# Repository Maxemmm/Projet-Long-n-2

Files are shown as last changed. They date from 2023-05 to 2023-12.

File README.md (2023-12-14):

# Room Monitoring Device - Projet Long n°2
## _EI2I4 HF_ | _Groupe 2_

The goal of this project is to develop a complete device that can measure several physical datas and to make them available through a Human Machine Interface (HMI) on an internet application. This project will allow to recover and format the data measured by the sensors and then send them to a server (Cloud) thanks to the long range and low power technology (LPWAN).

## Features
- Autonomous: Rechargeable LiPo battery and indoor solar panels as power source
- Communication of information by LPWAN network (LoRAWAN): Data sending every 10 minutes (configurable)
- On/off button : Allows an instantaneous measurement
- LED that lights up for a few seconds when the system is started.
- Data display in graphical form on an internet application: Ubidots STEM during the development phase and an internal Polytech website for the final rendering of the project.

## Components
In order to realize this project, we had to find components that best respond to the imposed specifications by focusing on the main constraint which is the low consumption of the system:

| Components | Price |
| --- | --- |
| [E-Ink Screen](https://www.digikey.fr/en/products/detail/adafruit-industries-llc/4197/10060730) | 21.10€ |  
| [Indoor solar kit](https://www.mouser.fr/ProductDetail/PowerFilm/DEV-BASIC?qs=BJlw7L4Cy7%2Fw4dHFXPm5kg%3D%3D) | 55.97€ |
| [CO2, T°, Humidity Sensor](https://www.digikey.fr/fr/products/detail/seeed-technology-co.,-ltd/101020952/14672116?utm_adgroup=&utm_source=google&utm_medium=cpc&utm_campaign=PMAX%20Shopping_Product_Development%20Board&utm_term=&productid=14672116&gclid=CjwKCAiA3KefBhByEiwAi2LDHGC3sSf3_wtaYPH630ib0XKAaLsoO_e8GBNamO-FCIEC66xhhMLAGhoCcFoQAvD_BwE) | 48.36€ |
| [Noise Sensor](https://www.gotronic.fr/art-module-micro-mems-fermion-sen0487-34167.htm) | 3.50€ |
| [Light Sensor](https://www.digikey.fr/fr/products/detail/adafruit-industries-llc/5378/16056942?productid=16056942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) | 4.64€ |
| [Battery](https://www.gotronic.fr/art-accu-lipo-3-7-vcc-1000-mah-pr523450-5813.htm) | 9.90€ |

For a total cost of 143.47€, we created [insert project name]. Responding to the specifications imposed, this energy autonomous system allows to manage the constants of a room in order to respect the sanitary conditions imposed by the school, or by any other organization.

## User interface
We used a Ubitdots STEM user interface which is a perfect environment to send data from our Arduino board to the cloud. The dashboard then allows the visualisation and monitoring of all this data remotely
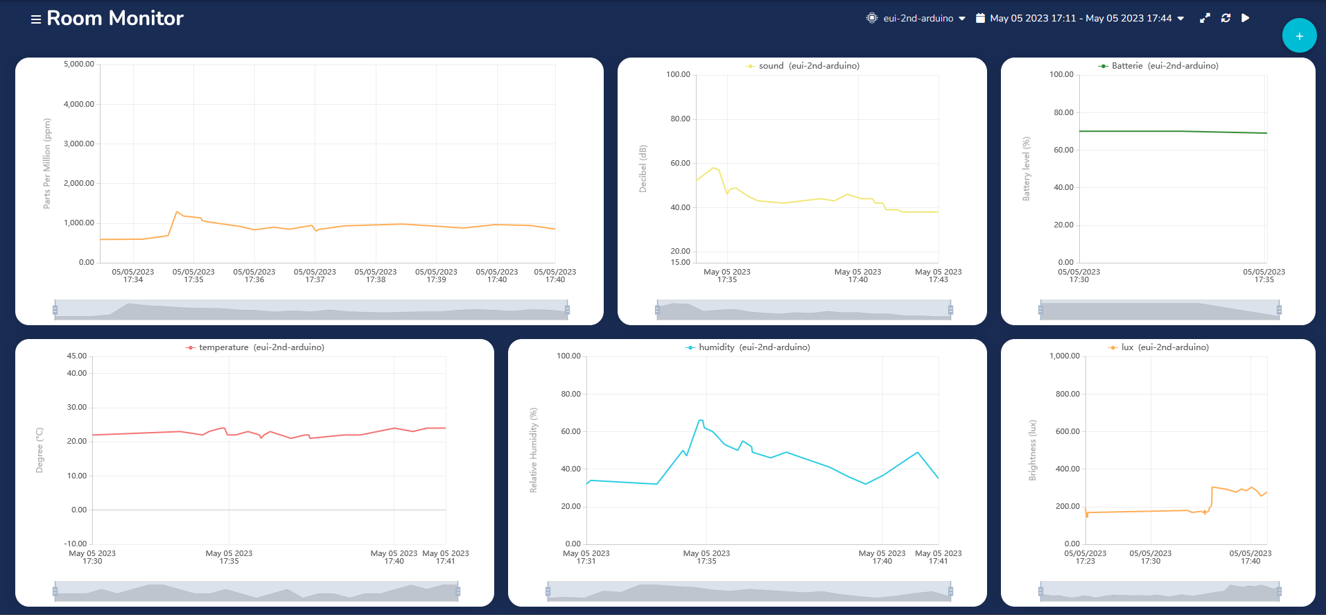
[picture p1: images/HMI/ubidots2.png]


## 3D Modeling
For this project I made a box to contain all the components as well as the PCB on which is mounted the Arduino MKR 1310 board and the indoors solar cells that allow the system to be self-sufficient in terms of energy.

### 3D Folder tree

```bash
.
├── Projet_rev11.f3z
├── Boitier_rev05.f3d
├── Bouton_rev01.f3d
├── Dos-Boitier_rev02.f3d
├── Panneau-Solaire-Haut_rev02
├── Panneau-Solaire-Haut
│   ├── Cache-Panneau-Solaire-Haut
│   └── Support-Panneau-Solaire-Haut
├── Panneau-Solaire-Cotes_rev04
└── Panneau-Solaire-Cotes
    ├── Cache-Panneau-Solaire-Cotes
    └── Support-Panneau-Solaire-Cotes
```

### 3D Model
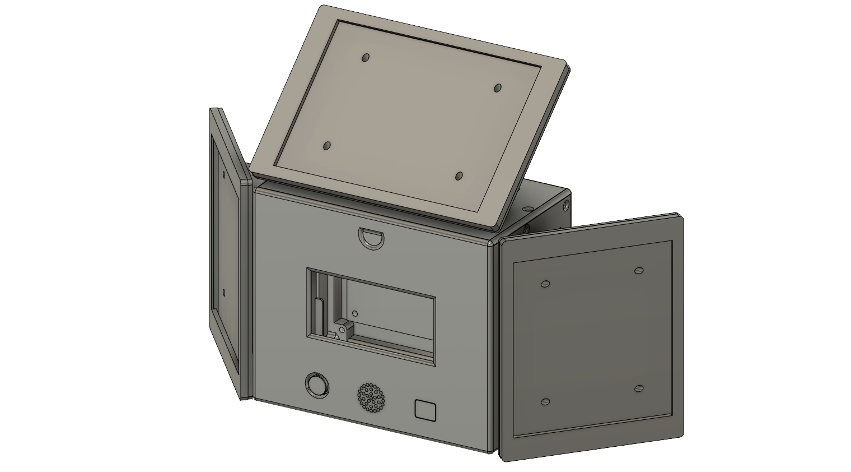
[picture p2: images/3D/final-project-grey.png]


<details>
<summary>Exploaded view</summary>

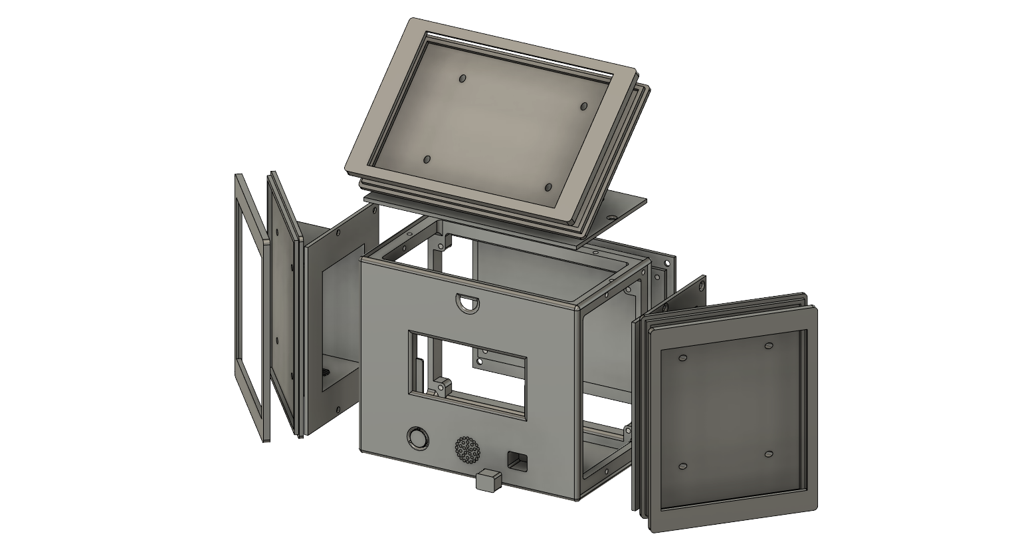
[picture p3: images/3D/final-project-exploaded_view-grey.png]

</details>

The model includes a total of 9 pieces:
| Part | Nb | Description |
| --- | --- | --- |
| Boitier | x1 | The box is the structure of the system and allows to hold the different components and sensors of the project. |
| Dos-Boitier | x1 | The back of the case is removable and allows to fix the PCB directly on it. By removing this part, you can access the inside of the box. |
| Bouton | x1 | The custom button allows instant measurement. |
| Support-Panneau-Solaire-Haut | x1 | This support must be fixed on the top of the box and allows to hold the upper solar panel. |
| Cache-Panneau-Solaire-Haut | x1 |This cover allows the top solar panel to be plated against the support. |
| Support-Panneau-Solaire-Cotes | x2 | This support must be fixed on the side of the box and allows to hold the side solar panel. |
| Cache-Panneau-Solaire-Cotes| x2 | This cover allows the side solar panel to be pressed against the support. |

### Assembling
To assemble the parts together you need the parts listed above as well as the material below:
| Hardware | Nb | Type |  Description |
| --- | --- | --- | --- |
| Screws | x16 | M3x8mm | Allows to fix the upper and lateral supports of the solar panels. |
| Anti-skid pads | x4 | 10x3mm | Allows to elevate the case and to give it more grip on the ground. |

## Electronic schematics
We have made a printed circuit board that allows us firstly to have a significant reduction in the number of wires inside the box that houses the system and secondly to be able to weld the components and connect the sensors to their intended locations.
<details>
<summary>Electrical scheme</summary>

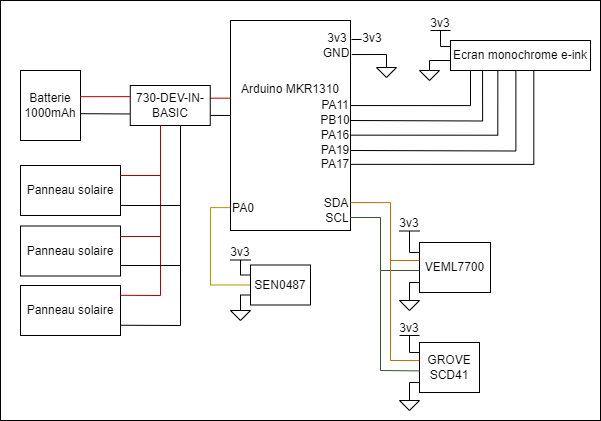
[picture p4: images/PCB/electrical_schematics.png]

</details>

<details>
<summary>Printed Circuit Board</summary>

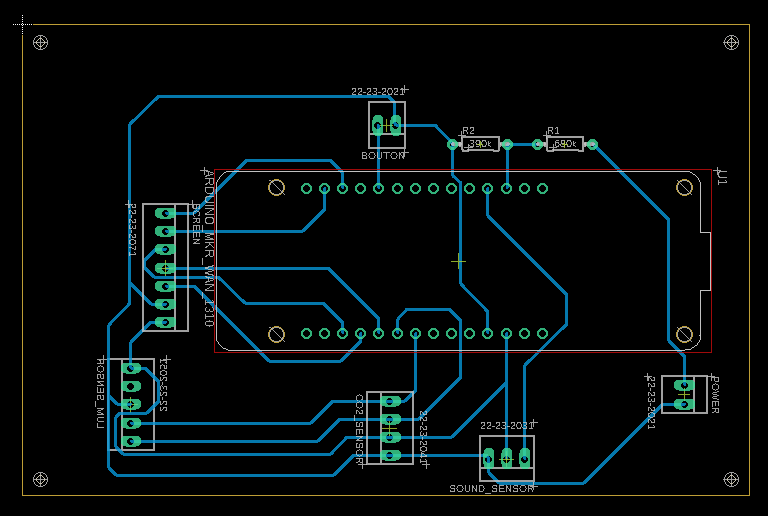
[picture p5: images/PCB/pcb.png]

</details>

## Consumption measurement
In this section, we will focus on the production and consumption of electricity. In order to make the device autonomous, we added the DEV-BASIC Powerfilm module, which includes two interior solar panels (we only used these), two exterior solar panels, an electronic board, and a battery. We also had two ECS300 solar panels available.

Therefore, we connected these four solar panels in parallel (to increase the current as much as possible) and connected them to the "Solar" input of the board. Then, we connected the battery to the "battery" output of the board and connected the "Vout" part of the board to the rest of the circuit.

Thanks to this setup, the solar panels continuously charge the battery, which then powers the board. Once the setup was completed, we measured the electricity production and found that our production was about 0.990mA/h on average (~380 lumens).

After that, we measured the consumption of the setup and found that it consumed an average of XXXX mA, thanks to code optimization and activated deep sleep and standby modes. <br>

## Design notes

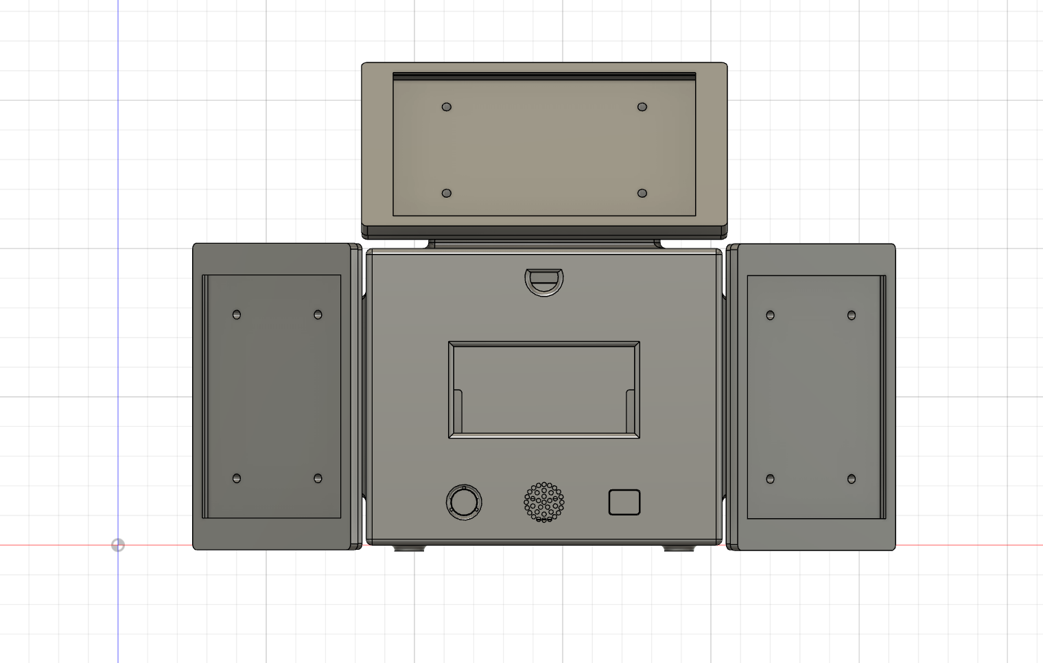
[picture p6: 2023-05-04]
images/3D/stock/front.png

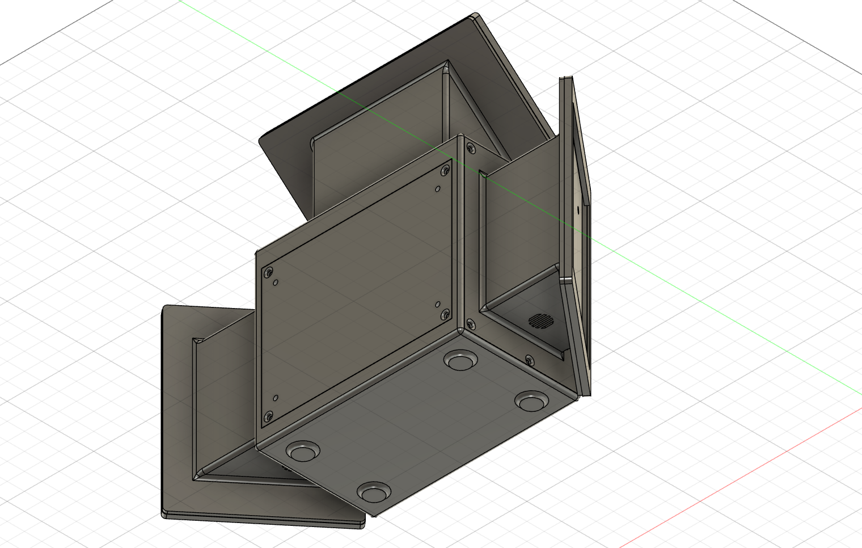
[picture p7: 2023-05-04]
images/3D/stock/back-bottom-right.png

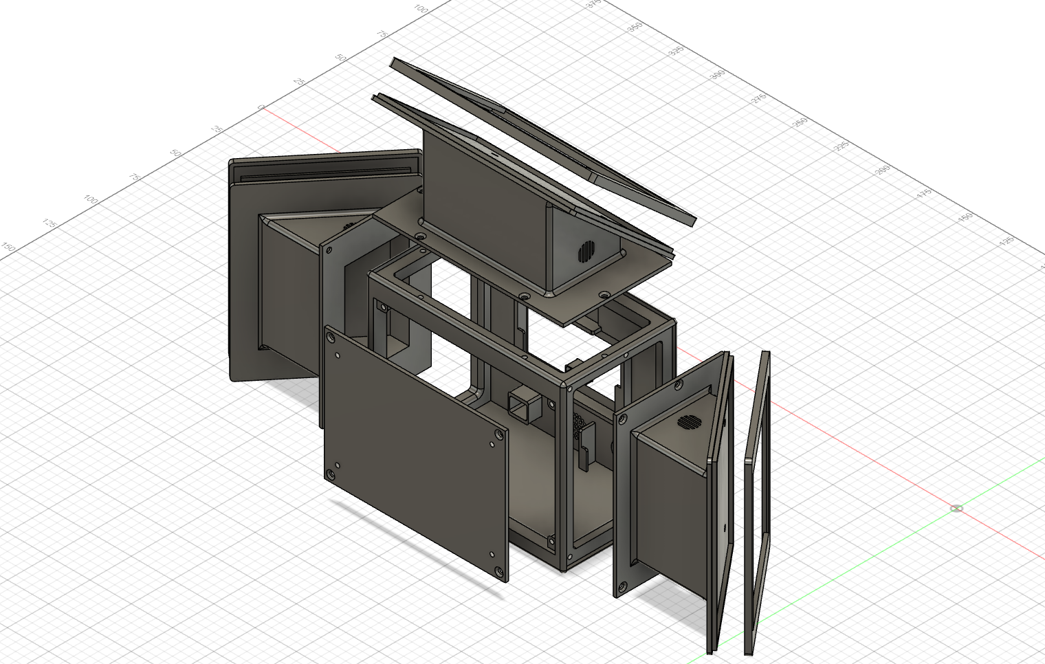
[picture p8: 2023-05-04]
images/3D/back-upper-right.png

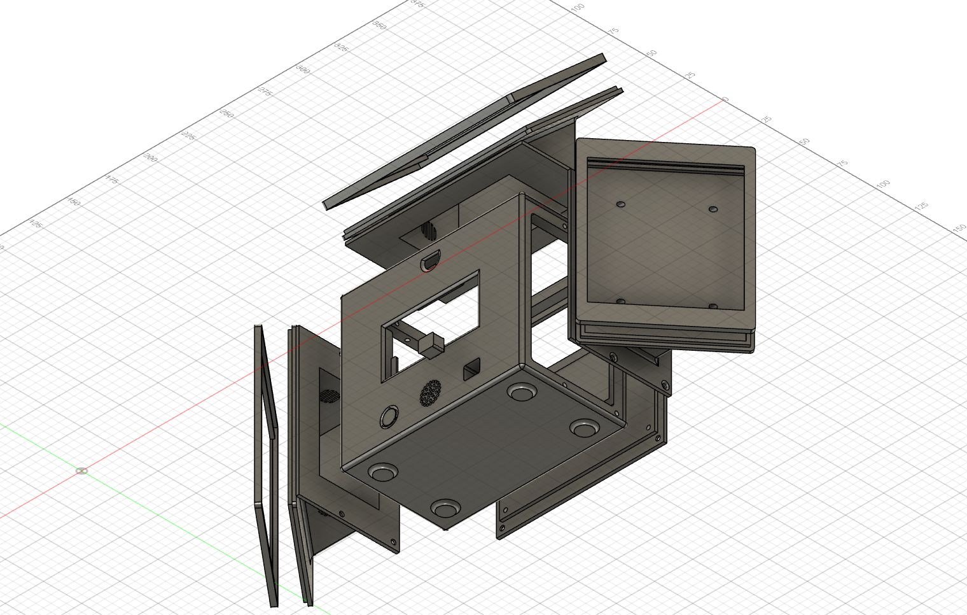
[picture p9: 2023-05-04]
images/3D/front-bottom-right.png

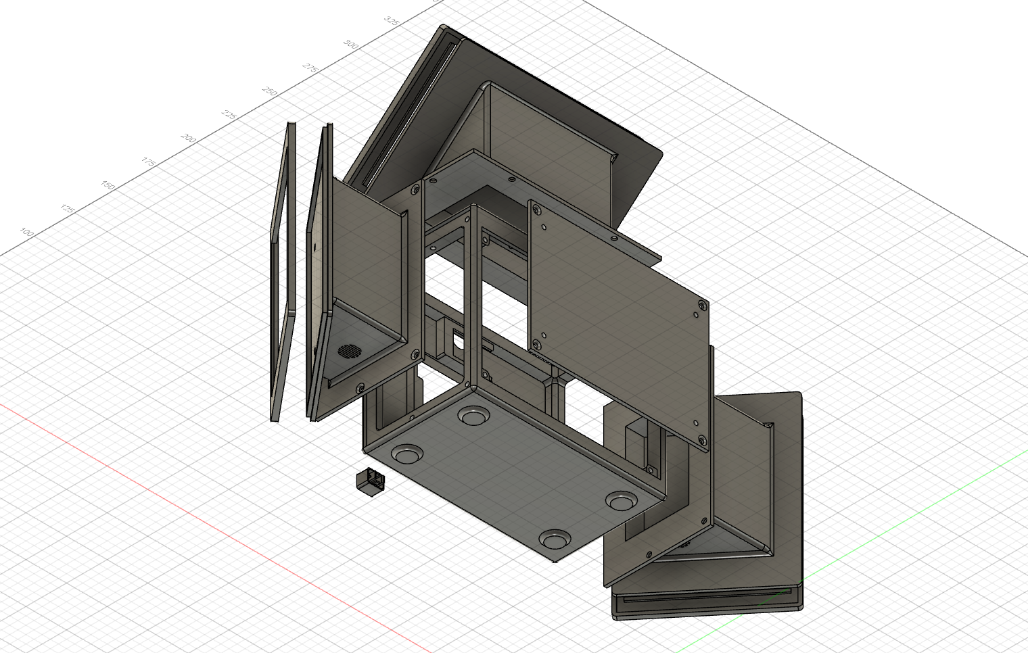
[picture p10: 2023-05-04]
images/3D/back-bottom-left.png

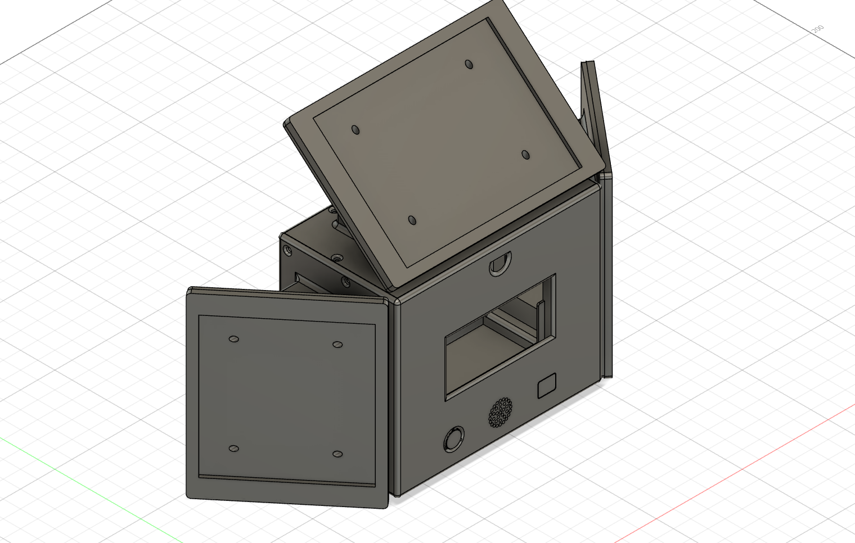
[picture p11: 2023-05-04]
images/3D/stock/front-upper-left.png

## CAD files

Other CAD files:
3D/Boitier_rev05.f3d
3D/Boitier_rev06.f3d
3D/Bouton_rev01.f3d
3D/Dos-Boitier_rev02.f3d
3D/Panneau-Solaire-Cotes/Cache-Panneau-Solaire-Cote.f3d
3D/Panneau-Solaire-Cotes/Support-Panneau-Solaire-Cote.f3d
3D/Panneau-Solaire-Cotes_rev04.f3d
3D/Panneau-Solaire-Cotes_rev05.f3d
3D/Panneau-Solaire-Haut/Cache-Panneau-Solaire-Haut.f3d
3D/Panneau-Solaire-Haut/Support-Panneau-Solaire-Haut.f3d
3D/Panneau-Solaire-Haut_rev02.f3d
3D/Panneau-Solaire-Haut_rev03.f3d
3D/Projet_rev11.f3z
3D/Projet_rev12.f3z

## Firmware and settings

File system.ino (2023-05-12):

#include <Arduino.h>
#include <SensirionI2cScd30.h> // SCD30 sensor
#include "Adafruit_VEML7700.h"
#include <Wire.h>
#include "Adafruit_ThinkInk.h"
#include <avr/dtostrf.h>
#include <stdlib.h>
#include <MKRWAN.h>
#include "ArduinoLowPower.h"
#include "system.h"

LoRaModem modem;
String appEui = "0000000000000000";
String appKey = "E6A69E487ABFDBF5CB20A3A96A9BE266";
Adafruit_VEML7700 veml = Adafruit_VEML7700();
SensirionI2cScd30 sensor;

scd30Sensor data1;
otherSensor data2;
systemConfigurationSettings device;

ThinkInk_213_Mono_BN display(EPD_DC, EPD_RESET, EPD_CS, SRAM_CS, EPD_BUSY);

// ---------------------------- DISPLAY MODE ---------------------------- //
# if DISPLAY_MODE == 1
  GFXcanvas1 co2Canvas((WIDTH/5), (HEIGHT/5));
  GFXcanvas1 tempCanvas((WIDTH/5), (HEIGHT/5));
  GFXcanvas1 humCanvas((WIDTH/5), (HEIGHT/5));
  GFXcanvas1 soundCanvas((WIDTH/5), (HEIGHT/5));
  GFXcanvas1 batteryCanvas((WIDTH/5), (HEIGHT/5));
# elif DISPLAY_MODE == 2
  GFXcanvas1 co2Canvas((WIDTH/2 - 5), (HEIGHT/3));
  GFXcanvas1 tempCanvas((WIDTH/4 + 12), (HEIGHT/5));
  GFXcanvas1 humCanvas((WIDTH/4 - 23), (HEIGHT/5));
  GFXcanvas1 batteryLogoCanvas(25, 12);
  GFXcanvas1 batteryCanvas(20, 10);
  GFXcanvas1 connexionLogoCanvas(20, 12);
  GFXcanvas1 alertHeaderCanvas(108, (HEIGHT/5 - 15));
  GFXcanvas1 alertMaxCO2Thresh(10, 10);
# endif
// ------------------------ END OF DISPLAY MODE ------------------------- //


// ------------------------------- SETUPS ------------------------------- //
void initializeLoRaWANGatewayConnexion() {
  // // Serial.println("[INFO] Starting LoRaWAN connexion...");
  if (!modem.begin(EU868)) {
    // // Serial.println("[ERROR] Failed to start LoRaWAN module.");
    while (1) {}
  };  

  Serial.print("[INFO] LoRaWAN module version is: ");
  // Serial.println(modem.version());
  Serial.print("[INFO] Device EUI is: ");
  // Serial.println(modem.deviceEUI());
  // Serial.println("[INFO] Trying to join TTN ...");
  int connected = modem.joinOTAA(appEui, appKey);

  if (!connected) {
    // Serial.println("[ERROR] Something went wrong; are you indoor? Move near a window and retry");
    while (1) {}
  } modem.minPollInterval(60);
  // NOTE: independently by this setting the modem will
  // not allow to send more than one message every 2 minutes,
  // this is enforced by firmware and can not be changed.
}

void initializeGroveSensor() {  
  // Serial.println("[DEBUG] Enterring Grove sensor init.");
  Wire.begin();
  sensor.begin(Wire, SCD30_I2C_ADDR_61);

  sensor.stopPeriodicMeasurement();
  sensor.setTemperatureOffset(10);
  sensor.setAltitudeCompensation(30);
  // sensor.softReset();
  delay(2000);
  // scd4x.begin(Wire); // enable connection
  // scd4x.reinit();

  // scd4x.setAmbientPressure(1013); // 1013 hPa
  // scd4x.setSensorAltitude(35); // 35 m
  // scd4x.setAutomaticSelfCalibration(1); // enable self calibration

  
  // error = scd4x.stopPeriodicMeasurement(); // stop potentially previously started measurement
  // if (error) {
  //   Serial.print("[ERROR] Could not execute stopPeriodicMeasurement(): ");
  //   errorToString(error, errorMessage, 256);
  //   // Serial.println(errorMessage);
  // }

  // error = scd4x.startLowPowerPeriodicMeasurement(); // get first measurement
  // if (error) {
  //   Serial.print("[ERROR] Could not execute startLowPowerPeriodicMeasurement(): ");
  //   errorToString(error, errorMessage, 256);
  //   // Serial.println(errorMessage);
  // }  
  error = sensor.startPeriodicMeasurement(0);
  if (error != NO_ERROR) {
    Serial.print("[ERROR] Could not execute startPeriodicMeasurement(): ");
    errorToString(error, errorMessage, sizeof errorMessage);
    // Serial.println(errorMessage);
    return;
  }
}

void initializeLuxSensor() {
  if (!veml.begin()) {
    // Serial.println("[ERROR] Lux sensor not found");
    // while (1);
  } else {
    // Serial.println("[INFO] Lux sensor found");    
  }
}

void initializeSensors() {
  initializeLuxSensor();
  veml.setLowThreshold(10000);
  veml.setHighThreshold(20000);
  veml.interruptEnable(true);
  // Serial.println("[ALERT] Lux sensor ready.");

  initializeGroveSensor();  
  // Serial.println("[ALERT] Grove sensor ready.");
}

void initializeScreen() {
  // Serial.println("[INFO] Adafruit eInk display setting up...");
  display.begin(THINKINK_MONO);
  display.clearBuffer();
  // Serial.println("[ALERT] Buffer has been cleared.");

  #if DISPLAY_MODE == 1
    // Serial.println("[INFO] Display mode 1 chosen.");
  #elif DISPLAY_MODE == 2
    // Serial.println("[INFO] Display mode 2 chosen.");
  #endif

  setupScreenOverlay();

  // Serial.println("[INFO] Display ready for use.");  
}
// --------------------------- END OF SETUP ----------------------------- //


// ------------------------------- SENSORS ------------------------------ //
double readNoiseLevel() {
  double pa_reference = 0.00002; // Référence pour le calcul de l'amplitude (Pa/LSB)
  double sensitivity = 66; // Gain de l'amplificateur du microphone
  double VCC = 5.0; // Tension d'alimentation du microphone (V)
  unsigned long startMillis = millis();  // Heure de début de l'échantillonnage
  unsigned int peakToPeak = 0;   // Mesure d'amplitude
  unsigned int signalMax = 0;
  unsigned int signalMin = 1024;
  int sampleWindow = 200; // La taille de la fenêtre d'échantillonnage (en millisecondes)
  unsigned int sample; // Valeur de l'échantillon
  
  // Acquisition de l'échantillon de son
  while (millis() - startMillis < sampleWindow) {
    sample = analogRead(microphonePin);
    if (sample < 1024) {
      if (sample > signalMax) {
        signalMax = sample;
      } else if (sample < signalMin) {
        signalMin = sample;
      }
    }
  }
  peakToPeak = (signalMax - signalMin);
  
  // Conversion RMS en dB
  double volts = (peakToPeak * VCC) / 1024;
  double vp = volts / 2; // Tension crête-à-crête
  double v_rms = vp / sqrt(2); // Tension efficace (RMS)
  double pa_rms = v_rms / sensitivity; // Pression acoustique efficace (RMS)
  return (20 * log10(pa_rms / pa_reference) + 20);
}

int readBatteryLevel() {
  const float R1 = 680000; // resistance value of R1 in ohms
  const float R2 = 390000; // resistance value of R2 in ohms
  const float Vin = 3.35; // input voltage to voltage divider
  float batteryVoltage = 0; // Variable pour stocker la tension de la batterie

  // Tableau de correspondance de la tension de la batterie au pourcentage de charge
  const float batteryVoltageTable[] = {3.0, 3.3, 3.6, 3.7, 3.75, 3.79, 3.83, 3.87, 3.92, 3.97, 4.1, 4.2};
  const int batteryPercentageTable[] = {0, 5, 10, 20, 30, 40, 50, 60, 70, 80, 90, 100};
  const int batteryTableSize = sizeof(batteryVoltageTable) / sizeof(batteryVoltageTable[0]);

  int sensorValue = analogRead(batteryPin); // Lire la valeur analogique de la broche A0
  float voltage = sensorValue * (3.35 / 1023.0); // Convertir la valeur analogique en tension

  // Calculer la tension de la batterie en utilisant le pont diviseur de tension
  batteryVoltage = voltage / (R2 / (R1 + R2));

  int batteryPercentage = 0;
  for (int i = 0; i < batteryTableSize - 1; i++) {
    if (batteryVoltage >= batteryVoltageTable[i] && batteryVoltage < batteryVoltageTable[i + 1]) {
      float slope = (float)(batteryPercentageTable[i + 1] - batteryPercentageTable[i]) / (batteryVoltageTable[i + 1] - batteryVoltageTable[i]);
      float offset = batteryPercentageTable[i] - slope * batteryVoltageTable[i];
      batteryPercentage = (int)(slope * batteryVoltage + offset);
      break;
    }
  }
  return batteryPercentage;
}

void readSensorsData() {
  // -------------------- SCD4X SENSOR -------------------- //
  // if (isSleep) {
  //   isSleep = false;
  //   scd4x.wakeUp();
  // }
  // uint16_t error;
  // char errorMessage[256];
  // error = scd4x.readMeasurement(data1.co2Value, data1.temperatureValue, data1.humidityValue);
  // if (error) {
  //   Serial.print("[ERROR] Couldn't execute readMeasurement(): ");
  //   errorToString(error, errorMessage, 256);
  //   // Serial.println(errorMessage);
  // } else if (data1.co2Value == 0) {
  //   // Serial.println("[ERROR] Invalid co2 sample detected.");
  // }
  // scd4x.powerDown();
  // isSleep = true;  
  // Serial.println("[DEBUG] Reading Grove sensor.");
  
  float co2SCD30 = 0.0;
  float tempSCD30 = 0.0;
  float humSCD30 = 0.0;

  delay(2000);

  error = sensor.blockingReadMeasurementData(co2SCD30, tempSCD30, humSCD30);
  if (error != NO_ERROR) {
    Serial.print("[ERROR] Could not execute blockingReadMeasurementData(): ");
    errorToString(error, errorMessage, sizeof errorMessage);
    // Serial.println(errorMessage);
  }

  if (co2SCD30 > 5000) {
    co2SCD30 = 5000;
    maxThresholdCO2 = true;
  } else {
    maxThresholdCO2 = false;
  }
  
  data1.co2Value = co2SCD30;
  data1.temperatureValue = tempSCD30;
  data1.humidityValue = humSCD30;
  // ------------------------------------------------------ //

  // -------------------- SOUND SENSOR -------------------- //
  // Serial.println("[DEBUG] Reading noise level sensor.");
  data2.noiseValue = readNoiseLevel();
  if (data2.noiseValue == 0) {
    Serial.print("[ERROR] Could not execute readNoiseLevel(): invalid value.");
  }
  // ------------------------------------------------------ //

  // --------------------- LUX SENSOR --------------------- //
  // Serial.println("[DEBUG] Reading luminosity sensor.");
  data2.luxValue = veml.readLux();  
  // ------------------------------------------------------ //
  // Serial.println("[DEBUG] Reading battery level.");
  data2.batteryValue = readBatteryLevel();
}
// --------------------------- END OF SENSORS --------------------------- //


// ------------------------------- ALERTS ------------------------------- //
void sensorAlertManager(uint8_t type, int value, int threshold) {
  switch(type) {
    case 0: // CO2
      if (value > threshold) {
        // Serial.println("[ALERT] CO2 level over the threshold!");
        
        alertHeaderCanvas.setTextSize(1);
        alertHeaderCanvas.fillScreen(0);
        alertHeaderCanvas.setCursor(0, 0);
        alertHeaderCanvas.print("[ALERT] CO2!");
        display.drawBitmap((WIDTH/2 - 45), 9, alertHeaderCanvas.getBuffer(), alertHeaderCanvas.width(), alertHeaderCanvas.height(), fontColorCO2, backgroundColorCO2);
      //   fontColorCO2 = EPD_WHITE;
      //   backgroundColorCO2 = EPD_BLACK;
      // } else {
      //   fontColorCO2 = EPD_BLACK;
      //   backgroundColorCO2 = EPD_WHITE;
      } break;

    case 1: // Temperature
      if (value > threshold) {
        // Serial.println("[ALERT] Temperature level over the threshold!");

        alertHeaderCanvas.setTextSize(1);
        alertHeaderCanvas.fillScreen(0);
        alertHeaderCanvas.setCursor(0, 0);
        alertHeaderCanvas.print("[ALERT] TEMPERATURE!");
        display.drawBitmap((WIDTH/2 - 55), 9, alertHeaderCanvas.getBuffer(), alertHeaderCanvas.width(), alertHeaderCanvas.height(), fontColorCO2, backgroundColorCO2);
        
      //   fontColorFooter = EPD_WHITE;
      //   backgroundColorFooter = EPD_BLACK;
      // } else {
      //   fontColorFooter = EPD_BLACK;
      //   backgroundColorFooter = EPD_WHITE;
      } break;

    case 2: // Humidity
      if (value > threshold) {
        // Serial.println("[ALERT] Humidity level over the threshold!");

        alertHeaderCanvas.setTextSize(1);
        alertHeaderCanvas.fillScreen(0);
        alertHeaderCanvas.setCursor(0, 0);
        alertHeaderCanvas.print("[ALERT] HUMIDITY!");
        display.drawBitmap((WIDTH/2 - 55), 9, alertHeaderCanvas.getBuffer(), alertHeaderCanvas.width(), alertHeaderCanvas.height(), fontColorCO2, backgroundColorCO2);
        
      //   fontColorFooter = EPD_WHITE;
      //   backgroundColorFooter = EPD_BLACK;
      // } else {
      //   fontColorFooter = EPD_BLACK;
      //   backgroundColorFooter = EPD_WHITE;
      } break;

    case 3: // Sound
      if (value > threshold) {
        // Serial.println("[ALERT] Sound level over the threshold!");
        // print to E-Ink display
      } break;
    
    case 4: // Luminosity
      if (value > threshold) {
        // Serial.println("[ALERT] Luminosity level over the threshold!");
        // print to E-Ink display
      } break;
    
    case 5: // Battery
      if (value < threshold) {
        // Serial.println("[ALERT] Battery level under the threshold!");

        alertHeaderCanvas.setTextSize(1);
        alertHeaderCanvas.fillScreen(0);
        alertHeaderCanvas.setCursor(0, 0);
        alertHeaderCanvas.print("[ALERT] BATTERY!");
        display.drawBitmap((WIDTH/2 - 45), 9, alertHeaderCanvas.getBuffer(), alertHeaderCanvas.width(), alertHeaderCanvas.height(), fontColorCO2, backgroundColorCO2);
        
      //   fontColorHeader = EPD_WHITE;
      //   backgroundColorHeader = EPD_BLACK;
      // } else {
      //   fontColorHeader = EPD_BLACK;
      //   backgroundColorHeader = EPD_WHITE;
      } break;

    default:
      break;      
  }
}
// --------------------------- END OF ALERTS ---------------------------- //


// ----------------------------- OVERLAYS ----------------------------- //
void headerOverlay() {
  // display.setCursor(((WIDTH/2) - (WIDTH/4) + 35), 5);
  // display.setTextSize(2);
  // display.setTextColor(EPD_BLACK);
  // // display.print("22:58");

  display.drawRoundRect(2, 2, (WIDTH - 4), (HEIGHT/5 - 4), 4, EPD_BLACK);

  // display.drawRect((WIDTH/2-60), 4, 120, (HEIGHT/5 - 8), EPD_BLACK); // alert header position
  
  display.drawRoundRect(2, (HEIGHT/5 + 2), (WIDTH - 4), (4 * HEIGHT/5 - 2), 4, EPD_BLACK);
  
  // display.drawRoundRect(2, (HEIGHT/5 + 2), (WIDTH - 4), (8 * HEIGHT/15 - 12), 4, EPD_BLACK);
  // display.drawRoundRect(2, (8 * HEIGHT/15 + 18), (WIDTH - 4), (4 * HEIGHT/15 + 6), 4, EPD_BLACK);
}

void co2ScreenOverlay() {
  // Serial.println("[INFO] Building co2 overlay...");

  #if DISPLAY_MODE == 1
    display.fillRect(2, 2, (WIDTH/3 - 4), (HEIGHT - 4), EPD_BLACK);
    display.fillRect(4, 4, (WIDTH/3 - 8), (HEIGHT - 8), EPD_WHITE);

    display.setTextSize(2);
    display.setTextColor(EPD_BLACK);
    display.setCursor(5, 5);
    display.print("CO2");

    display.setTextSize(1);
    display.setTextColor(EPD_BLACK);
    display.setCursor((WIDTH/4 - 4), (HEIGHT - 15));
    display.print("ppm");
  #elif DISPLAY_MODE == 2
    display.setCursor(18, (HEIGHT/2 - 5));
    display.setTextSize(2);
    display.setTextColor(fontColorCO2);
    display.print("CO");

    display.setCursor(42, (HEIGHT/2 + 5));
    display.setTextSize(1);
    display.setTextColor(fontColorCO2);
    display.print("2");

    display.setCursor((2*WIDTH/3 + 32), (HEIGHT/2 - 5));
    display.setTextSize(2);
    display.setTextColor(fontColorCO2);
    display.print("ppm");
  #endif

  // Serial.println("[INFO] CO2 overlay has been pushed.");
}

void temperatureScreenOverlay() {
  // Serial.println("[INFO] Building temperature overlay...");

  #if DISPLAY_MODE == 1
    display.fillRect((WIDTH/3 + 2), 2, (WIDTH/3 - 4), (HEIGHT/2 - 4), EPD_BLACK);
    display.fillRect((WIDTH/3 + 4), 4, (WIDTH/3 - 8), (HEIGHT/2 - 8), EPD_WHITE);

    display.setTextSize(1);
    display.setTextColor(EPD_BLACK);
    display.setCursor((WIDTH/3 + 5), 5);
    display.print("Temperature");

    display.setTextSize(1);
    display.setTextColor(EPD_BLACK);
    display.setCursor((2*WIDTH/3 - 14), (HEIGHT/2 - 15));
    display.print("C");
  #elif DISPLAY_MODE == 2
    setTemperatureLogo(17, 107, 5, 15);
    display.setCursor((WIDTH/2 - 18), 89);
    display.setTextSize(1);
    display.setTextColor(EPD_BLACK);
    display.print("o");
    display.setCursor((WIDTH/2 - 11), 92);
    display.setTextSize(2);
    display.setTextColor(EPD_BLACK);
    display.print("C");
  #endif

  // Serial.println("[INFO] Temperature overlay has been pushed.");
}

void humidityScreenOverlay() {
  // Serial.println("[INFO] Building humidity overlay...");

  #if DISPLAY_MODE == 1
    display.fillRect((WIDTH/3 + 2), (HEIGHT/2 + 2), (WIDTH/3 - 4), (HEIGHT/2 - 4), EPD_BLACK);
    display.fillRect((WIDTH/3 + 4), (HEIGHT/2 + 4), (WIDTH/3 - 8), (HEIGHT/2 - 8), EPD_WHITE);

    display.setTextSize(1);
    display.setTextColor(EPD_BLACK);
    display.setCursor((WIDTH/3 + 5), (HEIGHT/2 + 5));
    display.print("Humidity");

    display.setTextSize(1);
    display.setTextColor(EPD_BLACK);
    display.setCursor((2*WIDTH/3 - 14), (HEIGHT - 15));
    display.print("%");
  #elif DISPLAY_MODE == 2
    setHumidityLogo((WIDTH/2 + 46), 107, 5);

    display.setCursor((WIDTH/2 + 100), 92);
    display.setTextSize(2);
    display.setTextColor(EPD_BLACK);
    display.print("%");
  #endif

  // Serial.println("[INFO] Humidity overlay has been pushed.");
}

void decibelScreenOverlay() {
  // Serial.println("[INFO] Building decibel overlay...");

  #if DISPLAY_MODE == 1
    display.fillRect((2*WIDTH/3 + 2), 2, (WIDTH/3 - 4), (HEIGHT/2 - 4), EPD_BLACK);
    display.fillRect((2*WIDTH/3 + 4), 4, (WIDTH/3 - 8), (HEIGHT/2 - 8), EPD_WHITE);

    display.setTextSize(1);
    display.setTextColor(EPD_BLACK);
    display.setCursor((2*WIDTH/3 + 5), 5);  
    display.print("Decibel");

    display.setTextSize(1);
    display.setTextColor(EPD_BLACK);
    display.setCursor((WIDTH - 20), (HEIGHT/2 - 15));
    display.print("dB");
  #elif DISPLAY_MODE == 2
    // TODO
    // Serial.println("[WARNING] No decibel overlay for this display parameter.");
  #endif

  // Serial.println("[INFO] Decibel overlay has been pushed.");
}

void batteryScreenOverlay() {
  // Serial.println("[INFO] Building battery overlay...");
  
  #if DISPLAY_MODE == 1
    display.fillRect((2*WIDTH/3 + 2), (HEIGHT/2 + 2), (WIDTH/3 - 4), (HEIGHT/2 - 4), EPD_BLACK);
    display.fillRect((2*WIDTH/3 + 4), (HEIGHT/2 + 4), (WIDTH/3 - 8), (HEIGHT/2 - 8), EPD_WHITE);

    display.setTextSize(1);
    display.setTextColor(EPD_BLACK);
    display.setCursor((2*WIDTH/3 + 5), (HEIGHT/2 + 5));
    display.print("Battery");

    display.setTextSize(1);
    display.setTextColor(EPD_BLACK);
    display.setCursor((WIDTH - 15), (HEIGHT - 15));
    display.print("%");
  #elif DISPLAY_MODE == 2
    // TODO
    // Serial.println("[WARNING] No battery overlay in this configuration.");
  #endif

  // Serial.println("[INFO] Battery overlay has been pushed.");
}

void setupScreenOverlay() {
  headerOverlay();
  co2ScreenOverlay();
  temperatureScreenOverlay();
  humidityScreenOverlay();
  decibelScreenOverlay();
  batteryScreenOverlay();
  display.display();
}

void displayConnexionLogo(int16_t x, int16_t y) {
  display.drawFastVLine(x, (y + 8), 2, EPD_BLACK);
  display.drawFastVLine((x + 4), (y + 6), 4, EPD_BLACK);
  display.drawFastVLine((x + 8), (y + 4), 6, EPD_BLACK);
  display.drawFastVLine((x + 12), (y + 2), 8, EPD_BLACK);
  if (!elementSent || ONLINE_STATUS == 0) {
    display.drawLine((x - 2), (y + 5), (x + 2), (y + 1), EPD_BLACK);
    display.drawLine((x - 2), (y + 1), (x + 2), (y + 5), EPD_BLACK);
  }
}

void displayBatteryLogo(int16_t x, int16_t y, int batteryLevel) {
  display.drawRoundRect(x, y, 20, 10, 1, fontColorHeader);
  display.drawRoundRect((x + 19), (y + 2), 3, 6, 1, fontColorHeader);
  int w = (batteryLevel * 20)/100;
  display.fillRoundRect(x, y, w, 10, 1, fontColorHeader);
}

void setHumidityLogo(int x, int y, int r) {
  display.fillCircle(x, y, r, fontColorHeader); 
  display.fillTriangle((x - r + 1), (y - 4), (x + r - 1), (y - 4), x, (y - (r * 2) - 4), fontColorHeader);
  display.fillCircle(x, y, (r/2 + 1), backgroundColorFooter);
  display.fillTriangle((x - r + 2), (y-2), (x + r - 2), (y - 2), x, (y - (r*2) + 2), backgroundColorFooter);
}

void setTemperatureLogo(int x, int y, int r, int h) {
  display.fillCircle(x, (y), r, fontColorHeader);
  display.fillRoundRect((x - (r/2)), (y - 16), r, h, 2, fontColorHeader);
  display.drawFastVLine(x, (y - (h - 1)), (h - 2), backgroundColorFooter);
  display.drawFastHLine((x + (r/2) + 2), (y - 15), 4, fontColorHeader);
  display.drawFastHLine((x + (r/2) + 2), (y - 12), 2, fontColorHeader);
  display.drawFastHLine((x + (r/2) + 2), (y - 9), 2, fontColorHeader);
  display.drawFastHLine((x + (r/2) + 2), (y - 6), 4, fontColorHeader);
  display.fillCircle(x, (y), (r/2 + 1), backgroundColorFooter);
}
// -------------------------- END OF OVERLAYS ------------------------- //
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
void loop() { 
  // Serial.println("[DEBUG] Entering loop.");
  readSensorsData();
  // Serial.println("[DEBUG] readSensorsData() has been executed.");

  sensorAlertManager(0, data1.co2Value, device.co2Threshold);
  sensorAlertManager(1, data1.temperatureValue, device.temperatureThreshold);
  sensorAlertManager(2, data1.humidityValue, device.humidityThreshold);
  sensorAlertManager(3, data2.noiseValue, device.noiseThreshold); 
  sensorAlertManager(4, data2.luxValue, device.luxThreshold);
  sensorAlertManager(5, data2.batteryValue, device.batteryThreshold);

  displayDatasToTerminal(data1.co2Value, data1.temperatureValue, data1.humidityValue, data2.noiseValue, data2.luxValue, data2.batteryValue);
  displayDatasToScreen(data1.co2Value, data1.temperatureValue, data1.humidityValue, data2.noiseValue, data2.batteryValue);
  
  #if ONLINE_STATUS == 1
    // Serial.println("[DEBUG] Sending datas to IoT network.");
    dataTransmission(data1.co2Value, data1.temperatureValue, data1.humidityValue, data2.noiseValue, data2.luxValue, data2.batteryValue);
  #endif

  display.display();
  // Serial.println("[INFO] Displaying datas.");

  // Serial.println("[ALERT] Standby mode until next measurement.\n");
  //delay(device.measuringFrequency); // wait
  LowPower.sleep(device.measuringFrequency);


  #if ONLINE_STATUS == 1
    dataReception();
  #endif
}

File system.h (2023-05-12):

#ifndef SYSTEM_H
#define SYSTEM_H

// -------------- CUSTOM DEFINES --------------- //
#define ONLINE_STATUS 0 // ONLINE: 1, OFFLINE: 0

// -------------- DISPLAY DEFINES -------------- //
#define EPD_CS      4
#define EPD_DC      3
#define SRAM_CS     -1
#define EPD_RESET   -1 // can set to -1 and share with microcontroller Reset!
#define EPD_BUSY    -1 // can set to -1 to not use a pin (will wait a fixed delay)

#define DISPLAY_MODE 2 // display setup

// -------------- THRESHOLDS DEFINES -------------- //
#define CO2_THRESHOLD 1000
#define TEMP_THRESHOLD 30
#define HUM_THRESHOLD 60
#define NOISE_THRESHOLD 60
#define LUX_THRESHOLD 1000
#define BATT_THRESHOLD 20

// -------------- GLOBAL VARIABLES -------------- //
/* Display */
int WIDTH = 250;
int HEIGHT = 122;
uint16_t fontColorCO2 = EPD_BLACK;
uint16_t backgroundColorCO2 = EPD_WHITE;
uint16_t fontColorHeader = EPD_BLACK;
uint16_t backgroundColorHeader = EPD_WHITE;
uint16_t fontColorFooter = EPD_BLACK;
uint16_t backgroundColorFooter = EPD_WHITE;

/* Arduino Pins */
const int batteryPin = A1;
const int microphonePin = A2;
const int interruptPin = 1;

/* Unsorted variables */
static char errorMessage[128];
static int16_t error;
// bool isSleep = false;
const int SCD_ADDRESS = 0x62;
volatile bool elementSent = false;
volatile bool maxThresholdCO2 = false;


// -------------- STRUCTURES -------------- //
struct scd30Sensor {
  uint16_t co2Value;
  float temperatureValue,
        humidityValue;
};

struct otherSensor {
  double noiseValue = 0;
  int luxValue = 0,
      batteryValue;
};

struct systemConfigurationSettings {
  unsigned long measuringFrequency = 60000; // measuring every 1 minutes
  int co2Threshold = CO2_THRESHOLD, // (ppm)
      temperatureThreshold = TEMP_THRESHOLD, // (°C)
      humidityThreshold = HUM_THRESHOLD, // (%)
      noiseThreshold = NOISE_THRESHOLD, // (dB)
      luxThreshold = LUX_THRESHOLD, // (LUX)
      batteryThreshold = BATT_THRESHOLD; // (%)
};

// -------------- FUNCTION DECLARATIONS -------------- //

/* Setups */
void initializeLoRaWANGatewayConnexion();
void initializeGroveSensor();
void initializeLuxSensor();
void initializeSensors();
void initializeScreen();

/* Sensors datas acquirement */
double readNoiseLevel();
int readBatteryLevel();
void readSensorsData();

/* Alert sensor management */
void sensorAlertManager(uint8_t type, int value, int threshold);

/* Display overlay initilization */
void headerOverlay();
void co2ScreenOverlay();
void temperatureScreenOverlay();
void humidityScreenOverlay();
void decibelScreenOverlay();
void batteryScreenOverlay();
void setupScreenOverlay();
void displayConnexionLogo(int16_t x, int16_t y);
void displayBatteryLogo(int16_t x, int16_t y, int batteryLevel);
void setHumidityLogo(int x, int y, int r);
void setTemperatureLogo(int x, int y, int r, int h);

/* Display values */
void displayDatasToScreen(float co2Sensor, float tempSensor, float humSensor, double noiseSensor, int batteryLevel);
void displayDatasToTerminal(float co2Sensor, float tempSensor, float humSensor, double noiseSensor, int luxSensor, int batteryLevel);

/* LoRaWAN Tx & Rx */
#if ONLINE_STATUS == 1
  void dataTransmission(float co2Sensor, float tempSensor, float humSensor, double noiseSensor, int luxSens, int batteryLevel);
  void dataReception();
#endif

/* Button callback interruption */
void buttonISR();

/* Change sensor treshold */
// TODO

#endif
